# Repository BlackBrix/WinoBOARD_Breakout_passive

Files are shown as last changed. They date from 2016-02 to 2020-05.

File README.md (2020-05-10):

## Breakout-Board (passive) for the Wino-Board

This is a breadboard compatible Breakout-Board for the WinoBOARD (http://wino-board.com).  
The WinoBOARD comes with 2.0 mm spaced pin headers, so you can NOT use it with any standard (solder-less) breadboard / prototyping PCB (stripes or holes) out of the box...

### Features:
* pin spacing 0,1 inch / 100 mil / 2,54 mm
* 900 mil (22.86 mm) spacing between the 2 outer rows of pin headers
* therefore it fits on every standard (solder-less) breadboard / prototyping PCB (stripes or holes)
* smallest possible size: 25,4 mm x 35,56mm (1 inch x 1,4 inch)
* "sorted" I/Os (see picture)
* you may solder the WinoBOARD directly onto the this Breakout-Board or use (2mm-pin-spacing) sockets (recommended)
* cut-out in ground-plane for not disturbing the WiFi antenna
* has 2 mounting holes [2,2 mm] for M2-screws (e.g. for later use within another housing / or with your own projects)

This Breakout-Board is completely "passive" (no active components),  
that means, you have to manage the power supply (3.3V) and USB-connection and reset-button by yourself,  
or you use the USB-/Battery upgrade (http://wino-board.com/upgrades/usb-battery-upgrade)  
which is of course usable (stackable) with this Breakout-Board as well.

---

[I am in no way associated with the manufacturer of the original WinoBOARD]

get one -> [https://www.tindie.com/stores/blackbrix/](https://www.tindie.com/stores/blackbrix/)

---

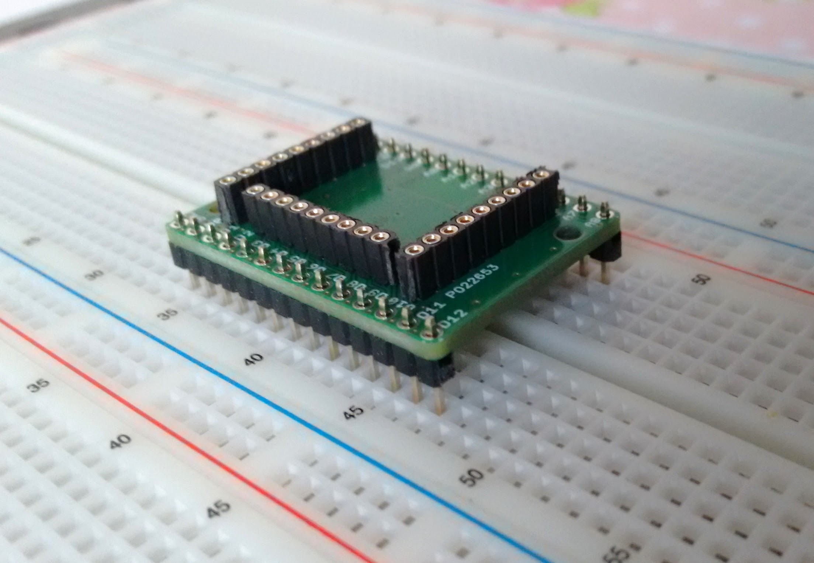
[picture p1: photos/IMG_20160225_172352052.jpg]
Breakout Board


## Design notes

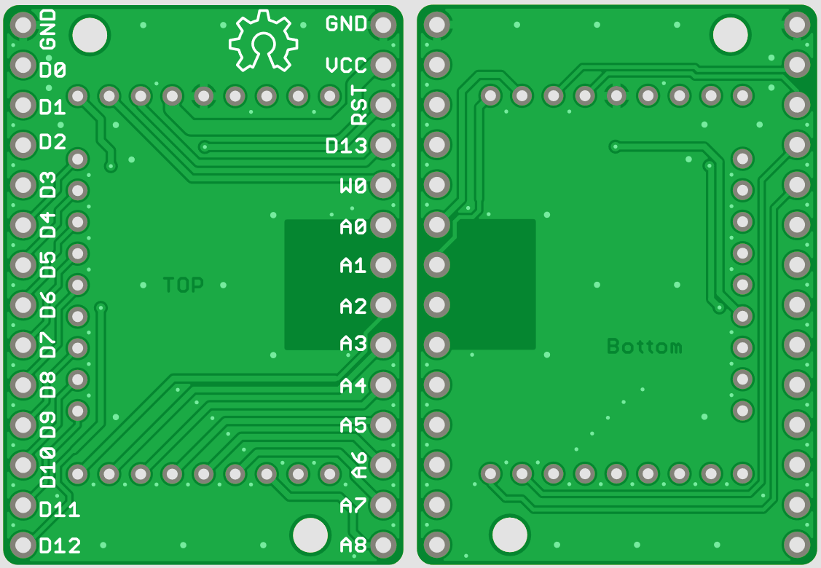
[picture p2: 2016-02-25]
hardware/Wino_Breakout_Passive_V1.0.png

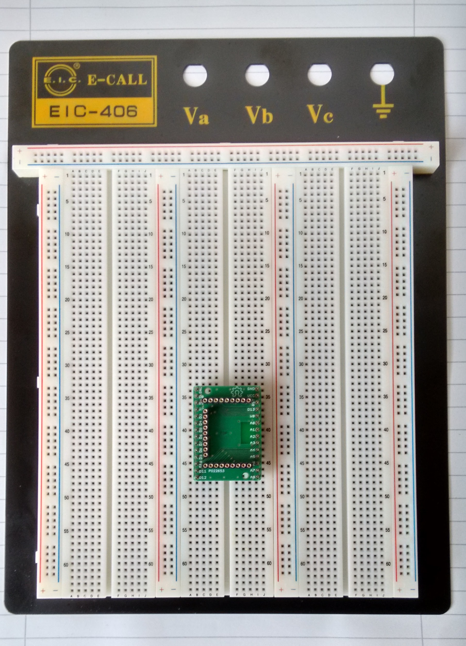
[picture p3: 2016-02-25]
photos/IMG_20160225_172307101_HDR.jpg

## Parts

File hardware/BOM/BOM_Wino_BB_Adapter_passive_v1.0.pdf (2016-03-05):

## BOM: Wino Breadboard Adapter passive v1.0

Pos. | Qty. | Bezeichnung | Supplier | Supplier Part No. | Manufacturer | Manufacturer Part No. | datasheet link
01 | 1 | PCB | Eurocircuits.com | P022653 | Eurocircuits | P022653 | -/-
02 | 2 | Pin-Header 2.54mm 14P. | Reichelt.com | SL 1X36G 2,54 | China (?) | -/- | https://github.com/BlackBrix/WinoBOARD_Breakout_passive/blob/master/hardware/component-datasheets/Reichelt_SL_1x50G_254.pdf
03 | 3 | Socket 2mm 9P. | Conrad.de | 739638 | Fischer Elektronik | BLY 1/50 | https://github.com/BlackBrix/WinoBOARD_Breakout_passive/blob/master/hardware/component-datasheets/Fischer_Elektronik_BLY1_2mm.pdf

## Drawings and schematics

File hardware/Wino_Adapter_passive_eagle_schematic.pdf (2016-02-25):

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

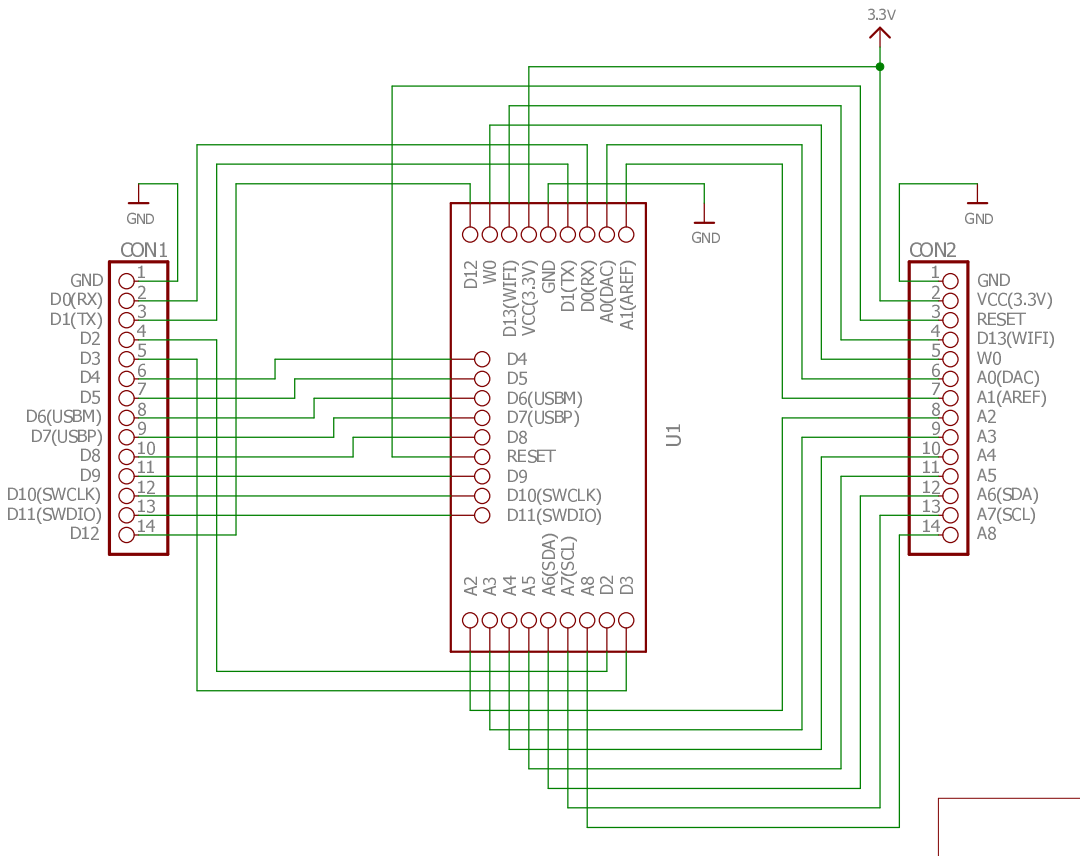
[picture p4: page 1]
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

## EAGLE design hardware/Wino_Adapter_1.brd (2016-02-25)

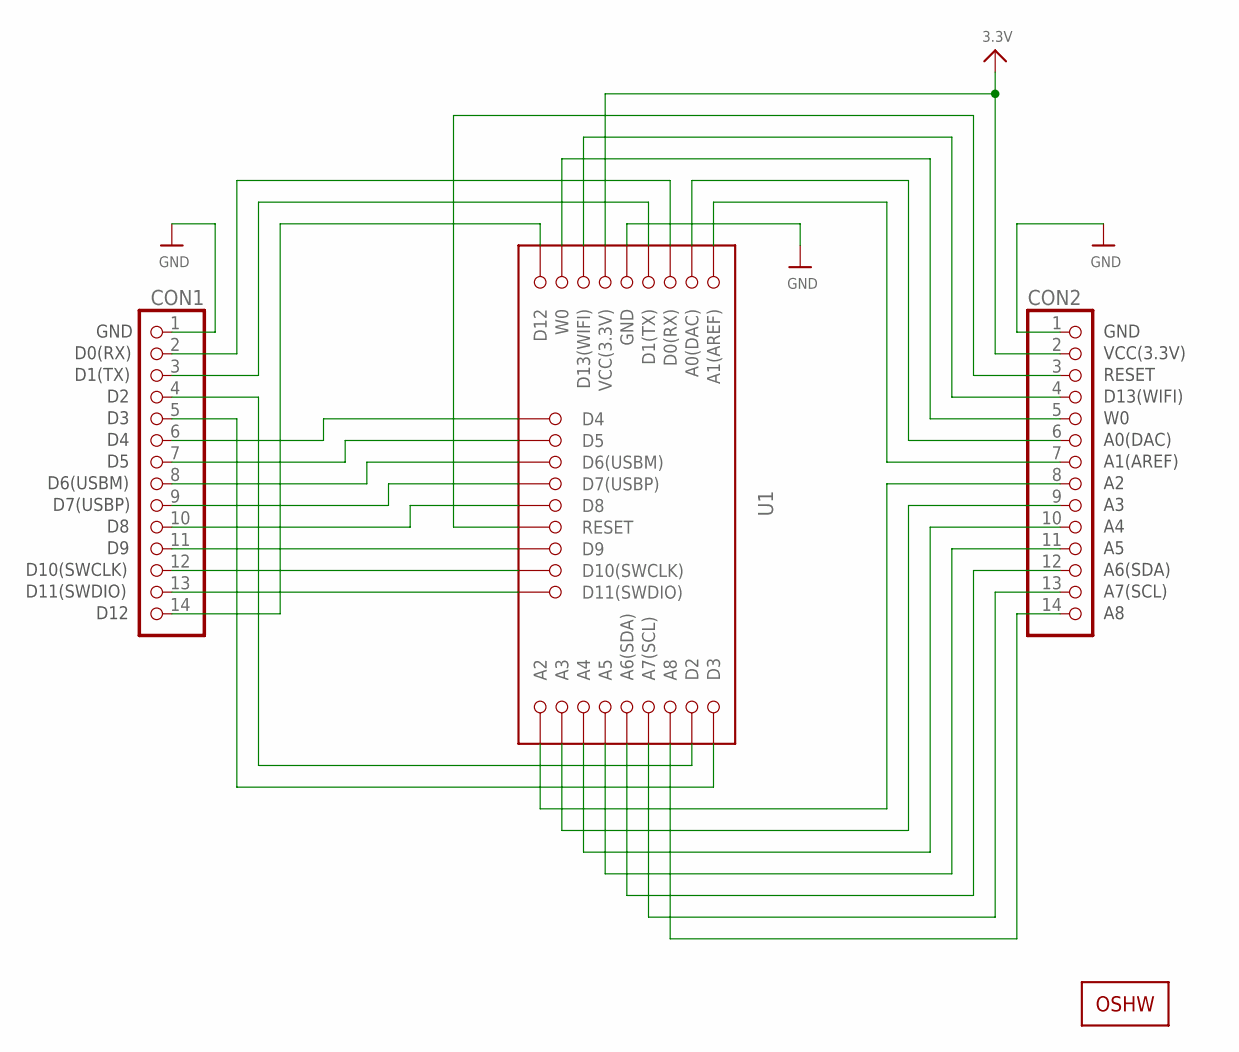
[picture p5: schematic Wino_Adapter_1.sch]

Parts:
CON1, CON2: HEADER-1X14; 1X14_ROUND_70
LOGO1: OSHW_LOGOX0150; OSHW_6X150
U1: WINO_BOARD_EINLOET

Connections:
3.3V: CON2.2, U1.VCC (VCC(3.3V))
GND: CON1.1, CON2.1, U1.GND
unnamed: CON1.2, U1.D0 (D0(RX))
unnamed: CON1.3, U1.D1 (D1(TX))
unnamed: CON1.4, U1.D2
unnamed: CON1.5, U1.D3
unnamed: CON1.6, U1.D4
unnamed: CON1.7, U1.D5
unnamed: CON1.8, U1.D6 (D6(USBM))
unnamed: CON1.9, U1.D7 (D7(USBP))
unnamed: CON1.10, U1.D8
unnamed: CON1.13, U1.D11 (D11(SWDIO))
unnamed: CON1.12, U1.D10 (D10(SWCLK))
unnamed: CON1.11, U1.D9
unnamed: CON1.14, U1.D12
unnamed: CON2.4, U1.D13(WIFI)
unnamed: CON2.6, U1.A0 (A0(DAC))
unnamed: CON2.7, U1.A1 (A1(AREF))
unnamed: CON2.8, U1.A2
unnamed: CON2.9, U1.A3
unnamed: CON2.10, U1.A4
unnamed: CON2.11, U1.A5
unnamed: CON2.12, U1.A6 (A6(SDA))
unnamed: CON2.13, U1.A7 (A7(SCL))
unnamed: CON2.14, U1.A8
unnamed: CON2.3, U1.RESET
unnamed: CON2.5, U1.W0

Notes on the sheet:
D0(RX)
D1(TX)
D6(USBM)
D7(USBP)
D10(SWCLK)
D11(SWDIO)
D12
GND
VCC(3.3V)
RESET
D13(WIFI)
A0(DAC)
A1(AREF)
A6(SDA)
A7(SCL)

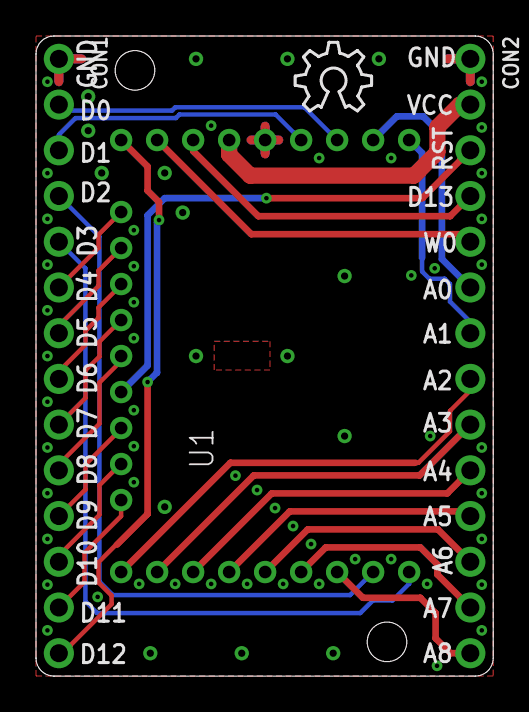
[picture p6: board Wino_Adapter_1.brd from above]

Board: 2 copper layers, 25.4 x 35.6 mm, 4 parts (0 on the bottom side), 27 nets.

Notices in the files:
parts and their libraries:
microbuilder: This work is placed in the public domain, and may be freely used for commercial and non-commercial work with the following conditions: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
